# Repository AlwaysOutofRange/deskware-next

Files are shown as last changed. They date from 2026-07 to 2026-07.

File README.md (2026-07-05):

# DeskWare Next

A modular, fully parameterized fork of DeskWare (design by Hands on Katie,
OpenSCAD by BlackjackDuck). Same design language, new architecture: every
part is generated from parameters, so storage systems of **any dimensions**
can be produced — no more fixed 196 mm plates. With default settings, parts
remain print-interchangeable with original DeskWare.

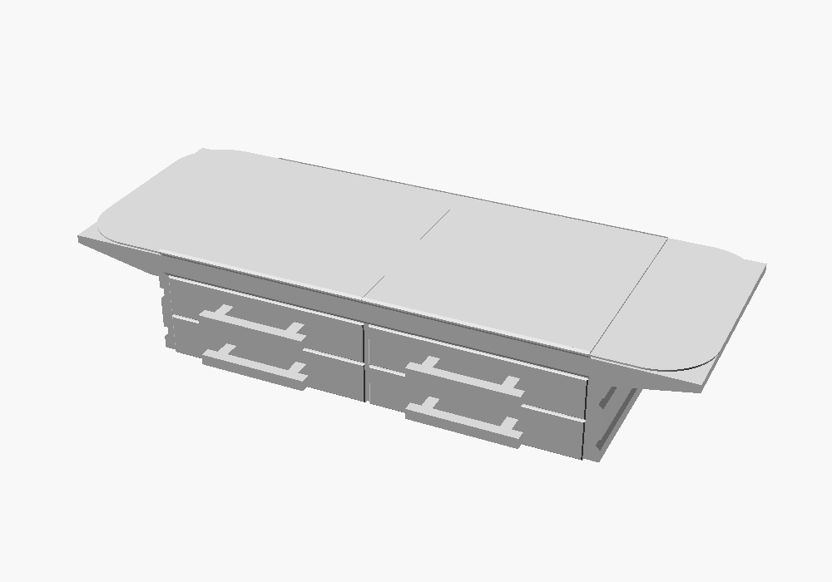
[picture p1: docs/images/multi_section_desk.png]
Two-section desk system


## Requirements

- OpenSCAD (recent version; developed against 2026.06)
- [BOSL2](https://github.com/BelfrySCAD/BOSL2) on the OpenSCAD library path
- The experimental `roof` feature enabled (GUI: Preferences → Features →
  roof; CLI: `--enable=roof`) — the end caps use it, and OpenSCAD silently
  renders them incomplete without it

## Quick start

```scad
include <deskware-next.scad>

//a whole system in one call...
storage_system(sections = 2, width = 196, depth = 196.5, total_height = 107.5);

//...or any single part at any size
base_plate(width = 250);
drawer(height_units = 2, rows = 2, columns = 3);

//too big for your printer? cut it, with mating connectors at the seams
split_part(size = [420, 211, 9.5], gap = 20)
    top_plate(width = 420, anchor=BOT);
```

Or open **`examples/customizer.scad`** in OpenSCAD and use the Customizer
panel: pick a part, set the dimensions, export.

Defaults live in [`config.scad`](config.scad) — including your print bed
size (`MAX_PRINT_WIDTH`/`MAX_PRINT_DEPTH`); parts warn when they exceed it.
The full API is documented in [`docs/reference.md`](docs/reference.md).

### Single-file build

Platforms like MakerWorld's parametric maker lab accept only one `.scad`
file. `tools/flatten.py` inlines all project includes (keeping the BOSL2
ones, which such platforms provide) into a self-contained, geometrically
identical build. Framework internals are hidden from the Customizer panel;
`--expose` keeps a file's sections visible — exposing `config.scad` gives
the full options panel (walls, top plate, drawer mounting, colors, …):

```bash
python3 tools/flatten.py examples/customizer.scad -o build/deskware-next-makerworld.scad \
    --expose config.scad \
    --hide-section "Core Dimensions" --hide-section "Print Bed" \
    --hide-section "End Style" --hide-section "Curve Sections" --hide-section "Connectors"
```

(The hidden sections are the ones the customizer entry re-exposes with its
own parameters, plus ones meaningless on an online platform.)

## Examples

| | |
| --- | --- |
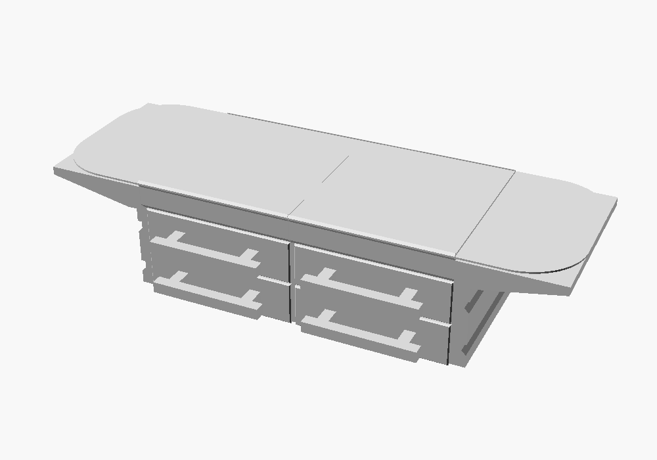
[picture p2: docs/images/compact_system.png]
|  **[multi_section_desk](examples/multi_section_desk.scad)** — the classic two-section desk system, one `storage_system()` call |  **[compact_system](examples/compact_system.scad)** — the same modules at 140 mm: every part prints whole on a small bed |
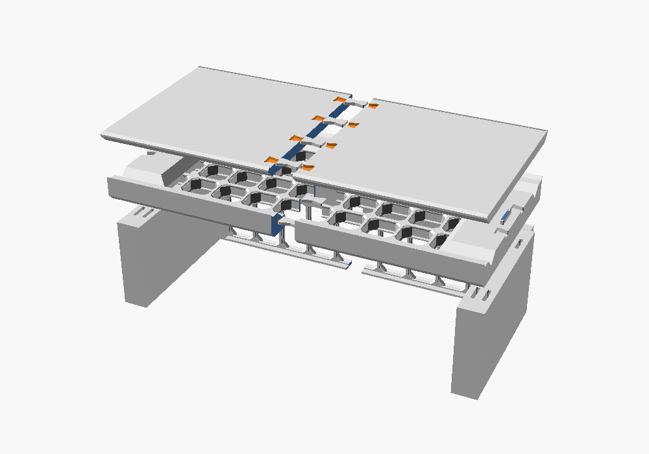
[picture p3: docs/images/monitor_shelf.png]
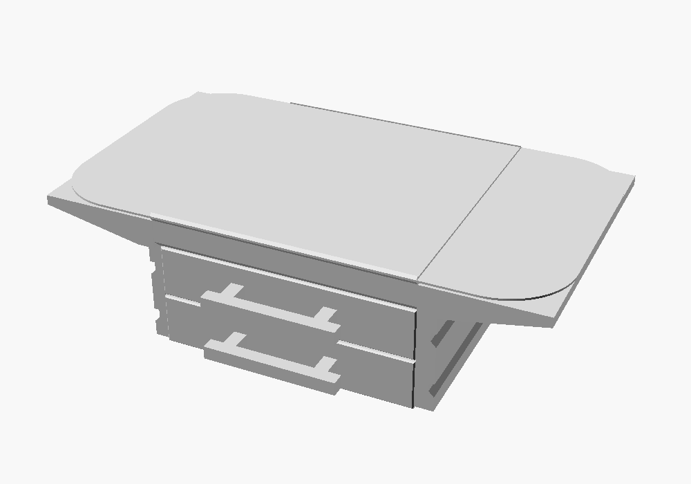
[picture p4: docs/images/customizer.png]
|  **[monitor_shelf](examples/monitor_shelf.scad)** — a 300 mm shelf, plates and backer auto-split with dovetail keys |  **[customizer](examples/customizer.scad)** — interactive part generator via the OpenSCAD Customizer |
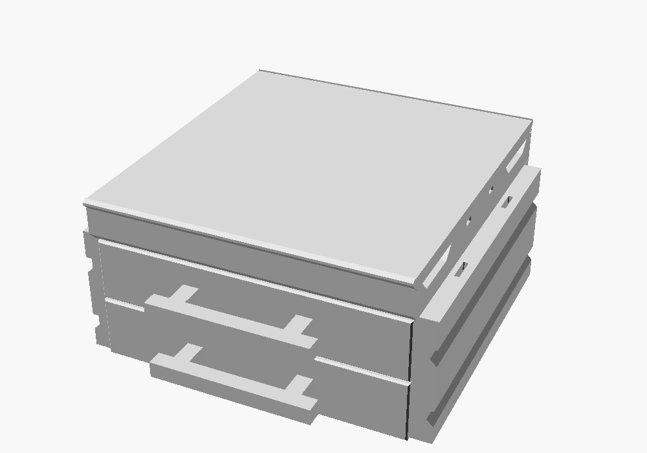
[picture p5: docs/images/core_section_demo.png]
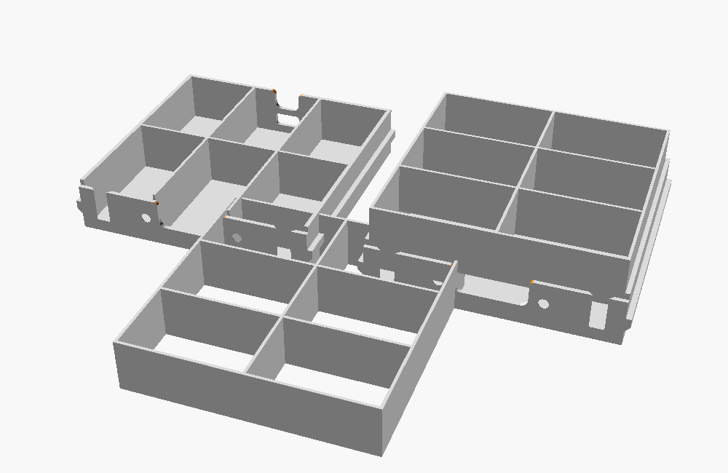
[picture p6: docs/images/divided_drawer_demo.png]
|  **[core_section_demo](examples/core_section_demo.scad)** — one full core section, placements derived from config |  **[divided_drawer_demo](examples/divided_drawer_demo.scad)** — built-in `rows × columns` compartments and the drop-in `divider_insert()` |
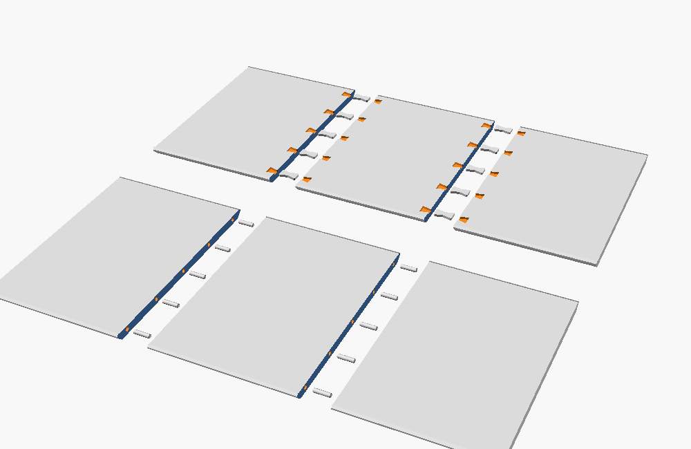
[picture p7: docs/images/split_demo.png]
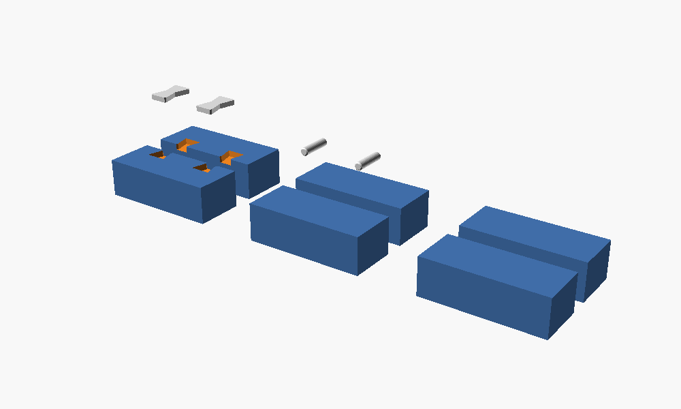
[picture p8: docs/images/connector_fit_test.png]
|  **[split_demo](examples/split_demo.scad)** — a 420 mm top plate split two ways (dovetails / hidden dowels) |  **[connector_fit_test](examples/connector_fit_test.scad)** — printable fit coupons for every seam connector style |
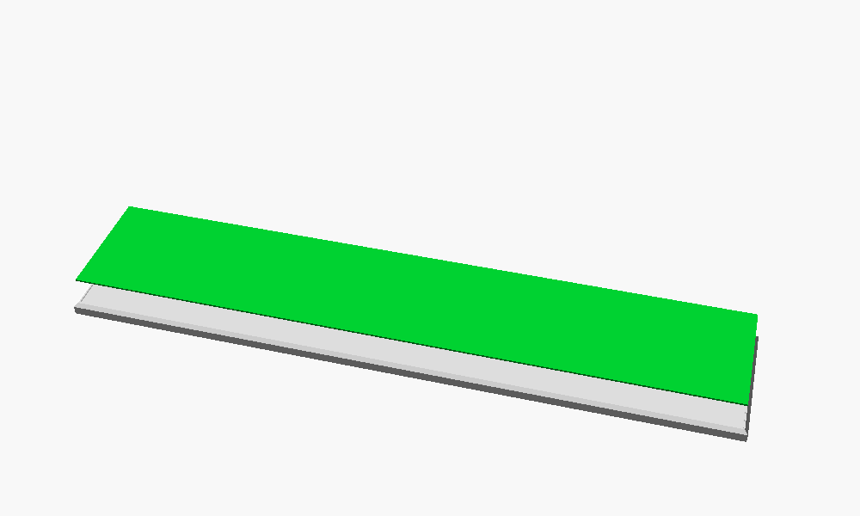
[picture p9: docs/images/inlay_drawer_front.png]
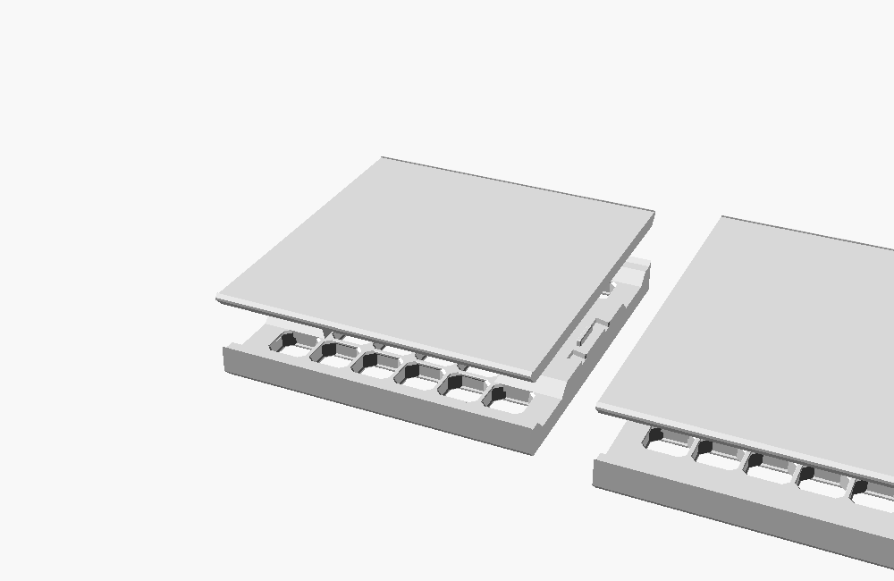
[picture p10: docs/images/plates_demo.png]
|  **[inlay_drawer_front](examples/inlay_drawer_front.scad)** — recessed drawer front with a printable contrast inlay |  **[plates_demo](examples/plates_demo.scad)** — base + top plates at default and arbitrary dimensions |
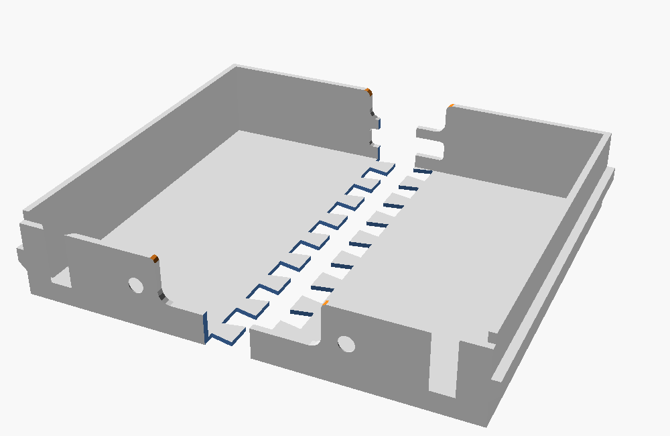
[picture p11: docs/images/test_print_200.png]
|  **[test_print_200](examples/test_print_200.scad)** — a complete 200 mm test system pre-split for a 175 mm bed: 2×2 grid splits with hidden dowels, puzzle glue seams for thin walls | |

## Structure

| Path | Contents |
| --- | --- |
| `config.scad` | User-facing parameters (dimensions, clearances, print bed, connectors, colors) |
| `core/` | Fixed system constants, pure derivation functions, print-fit checks, split system |
| `geometry/` | 2D cross-section profiles and sweep helpers |
| `connectors/` | HOK connectors, dovetails, dowels, magnets, tabs, slides, screws, seam joint API |
| `modules/` | The parts: plates, end caps, drawers + fronts, handle, riser, backer, dividers, `storage_system()` |
| `vendor/` | openGrid tiles (by David D), ported verbatim |
| `tools/` | Build helpers: `flatten.py` single-file build for MakerWorld-style platforms |
| `examples/` | Ready-to-render demos (see gallery above) |
| `docs/` | [Reference](docs/reference.md) and gallery images |
| `legacy/` | The original monolithic sources, unmodified — the regression oracle |

## Milestone status

- [x] **M1** — project structure, configuration system, shared utilities
- [x] **M2** — dynamic base/top plate generators
- [x] **M3** — dynamic drawer generator (plus riser and backer, completing the core section)
- [x] **M4** — dynamic divider system (`drawer(rows, columns)` + drop-in `divider_insert()`)
- [x] **M5** — connector system (`CONNECTOR_STYLE`-dispatched seam joints: dovetail, dowel, magnet)
- [x] **M6** — accessories: skipped by design — the plates carry standard openGrid fields, so the existing openGrid accessory ecosystem drops straight in
- [x] **M7** — automatic split generation for oversized parts (`split_part()` with seam connectors)
- [x] **M8** — documentation and examples

## Fidelity to the original

Every ported part was verified against the original sources (preserved in
[`legacy/`](legacy/)): STL exports at default dimensions match with zero
volume and bounding-box deltas, so DeskWare Next parts mate with original
DeskWare prints. See the provenance section of the
[reference](docs/reference.md).

## AI disclosure

The DeskWare Next refactor was written with substantial help from
[Claude Code](https://claude.com/claude-code), Anthropic's coding agent —
under human direction, with every part verified against the original
sources and validated in test prints.

## License

CC BY-NC-SA 4.0, inherited from the original DeskWare. See
[LICENSE.md](LICENSE.md) for attribution.

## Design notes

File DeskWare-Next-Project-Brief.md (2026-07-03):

# DeskWare Next -- Project Brief

## Overview

We are creating **DeskWare Next**, a fork of the original DeskWare
OpenSCAD project.

The goal is **not** to redesign the appearance of DeskWare. The goal is
to make the codebase modular, maintainable, and fully parameterized
while keeping the original design language.

DeskWare Next should allow users to generate storage systems of **any
dimensions**, instead of relying on fixed plate sizes like 196 mm.

------------------------------------------------------------------------

## Core Goals

-   Modular architecture
-   Clean OpenSCAD code
-   Minimal duplicated code
-   No magic numbers
-   Everything driven by parameters
-   Easy to extend
-   Easy to maintain
-   Easy to create new accessories

------------------------------------------------------------------------

## Design Philosophy

Instead of many specialized modules:

``` scad
drawer_small()
drawer_large()
drawer_xl()
plate_196()
plate_half()
```

Everything should become generic.

Example:

``` scad
plate(
    width = 180,
    depth = 180
);

drawer(
    width = 180,
    depth = 180,
    height = 60,
    rows = 2,
    columns = 3
);
```

------------------------------------------------------------------------

## Main Configuration

Every important dimension should come from a single configuration file.

Example:

``` scad
PLATE_WIDTH
PLATE_DEPTH

WALL_THICKNESS
BOTTOM_THICKNESS

CLEARANCE

CORNER_RADIUS

GRID_SIZE

MAGNET_DIAMETER
MAGNET_HEIGHT

PRINT_BED_SIZE

CONNECTOR_STYLE
```

Nothing should depend on hardcoded values.

------------------------------------------------------------------------

## Dynamic System

Every object should calculate its own dimensions.

Examples include:

-   Drawer wall spacing
-   Divider spacing
-   Grid placement
-   Clip locations
-   Magnet positions
-   Screw positions
-   Finger cutouts
-   Corner radii

All of these should derive from the parent object's dimensions.

------------------------------------------------------------------------

## Printer Independence

DeskWare Next should not assume any printer size.

Instead:

``` scad
MAX_PRINT_WIDTH
MAX_PRINT_DEPTH
```

If an object exceeds these dimensions it should automatically support
splitting into multiple printable pieces.

Future split methods:

-   Dowels
-   Dovetails
-   Puzzle joints
-   Magnet alignment

------------------------------------------------------------------------

## File Structure

``` text
deskware-next/

config.scad

core/
    constants.scad
    math.scad
    utilities.scad

geometry/
    rounded_box.scad
    fillets.scad
    chamfers.scad

connectors/
    dovetail.scad
    dowel.scad
    magnets.scad

modules/
    plate.scad
    drawer.scad
    organizer.scad
    riser.scad

accessories/
    pen_holder.scad
    tray.scad
    bins.scad

examples/
```

No 90,000-line single file.

------------------------------------------------------------------------

## Coding Standards

Every module should:

-   Have a clear purpose
-   Accept parameters
-   Avoid global state
-   Avoid duplicated calculations
-   Use descriptive variable names
-   Document parameters

Example:

``` scad
module drawer(
    width,
    depth,
    height,
    wall,
    clearance,
    rows,
    columns
)
```

------------------------------------------------------------------------

## Compatibility

Maintain the visual identity of the original DeskWare where practical.

Existing accessories should be portable with minimal changes.

Do not intentionally change aesthetics unless necessary.

------------------------------------------------------------------------

## Long-Term Vision

DeskWare Next should become a reusable framework rather than a fixed
collection of models.

Future additions may include:

-   Modular cable management
-   Monitor risers
-   Keyboard trays
-   Laptop stands
-   Shelving
-   Pegboard integration
-   Tool holders
-   Gridfinity compatibility
-   Parametric organizers

------------------------------------------------------------------------

## Development Strategy

Development should happen in small milestones.

### Milestone 1

-   Project structure
-   Configuration system
-   Shared utility functions

### Milestone 2

-   Dynamic plate generator

### Milestone 3

-   Dynamic drawer generator

### Milestone 4

-   Dynamic divider system

### Milestone 5

-   Connector system

### Milestone 6

-   Accessories

### Milestone 7

-   Automatic split generation

### Milestone 8

-   Documentation and examples

------------------------------------------------------------------------

## Guiding Principle

If a number appears more than once, it probably belongs in a parameter
or a shared calculation.

Every feature should be designed so changing a single dimension
propagates naturally throughout the model.

The end result should feel less like a collection of individual models
and more like a **parametric desk organization framework**.

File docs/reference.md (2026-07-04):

# DeskWare Next — Reference

Everything is included through the umbrella file:

```scad
include <deskware-next.scad>
```

All part modules follow the same conventions: **UPPER_SNAKE names in
`config.scad` are defaults**, every dimension is a parameter, parts are
BOSL2 `attachable` (they take `anchor` / `spin` / `orient` and compose with
`attach()`), and derived placements come from the pure functions in
`core/math.scad`. With unchanged config defaults, parts are dimensionally
interchangeable with original DeskWare prints (verified against the
original sources preserved in `legacy/`).

---

## Configuration (`config.scad`)

| Parameter | Default | Meaning |
| --- | --- | --- |
| `PLATE_WIDTH` / `PLATE_DEPTH` | 196 / 196.5 | Core section size, riser center to riser center. Any value — grid fields and connector positions adapt. |
| `TOTAL_HEIGHT` | 107.5 | Bottom of the risers to the top of the top plate. |
| `MAX_PRINT_WIDTH` / `MAX_PRINT_DEPTH` | *your bed* | Print bed limits; parts warn when exceeded, `split_part()` fixes it. |
| `WALL_THICKNESS` / `BOTTOM_THICKNESS` | 3 / 2 | Drawer walls and floors. |
| `CLEARANCE` | 0.15 | Fit clearance between mating parts. |
| `DIVIDER_THICKNESS` | 2 | Drawer compartment divider walls. |
| `CORNER_RADIUS` | 50 | Corner rounding of "Rounded Square" end pieces. |
| `END_STYLE` | `"Rounded Square"` | End cap style: `Rounded`, `Squared`, `Rounded Square`. |
| `TOP_PLATE_*` | — | Thickness, insert recess depth, lip width, chamfer, seating clearance. |
| `DRAWER_*` | — | Mounting method (printed handle / screw pulls), front chamfer, inlay recess. |
| `CONNECTOR_STYLE` | `"dovetail"` | Seam joint style: `dovetail`, `dowel`, `magnet`. |
| `CONNECTOR_SPACING` | 50 | Target distance between seam connectors. |
| `MAGNET_DIAMETER` / `MAGNET_HEIGHT` | 6 / 2 | Disc magnets for magnet seams. |
| `DOWEL_DIAMETER` / `DOWEL_LENGTH` | 4 / 16 | Printed dowel pins for dowel seams. |
| `BASE_PLATE_THICKNESS`, `RISER_WIDTH`, `ADDITIONAL_TOP_PLATE_SUPPORT`, `CURVE_RADIUS`, `VERBOSE` | — | Advanced. |

Interop-critical values (openGrid 28 mm unit, Gridfinity 42 mm, HOK
connector profile, dovetail/tab/slide dimensions, plate interface geometry)
live in `core/constants.scad` and should not normally be changed.

## Parts (`modules/`)

Every module accepts more parameters than shown — open the file for the
full documented signature. Deviating dimensions re-derive everything
inside (grid counts, connector spacings, slide counts).

```scad
//a whole system in one call (display composition)
storage_system(sections = 2, width = 196, depth = 196.5, total_height = 107.5);

//plates
base_plate(width = PLATE_WIDTH, depth = base_plate_depth(PLATE_DEPTH, BASEPLATE_DEPTH_EXTENSION));
top_plate(width = PLATE_WIDTH, thickness = 8.5, recess = 1);

//core section structure
riser(slide_sides = "BOTH", height = 80, chamfer = 0);
riser_split(height1 = 80, height2 = 40);        //stepped-height riser halves
backer(width = PLATE_WIDTH, height = 80);

//end caps (style: "Rounded", "Squared", "Rounded Square")
base_plate_end(style = END_STYLE, side = LEFT);
top_plate_end(style = END_STYLE, side = RIGHT);

//drawers
drawer(height_units = 1, rows = 2, columns = 3);  //built-in compartments
drawer_front(height_units = 1, recess = false);
drawer_handle();
divider_insert(rows = 3, columns = 2);            //drop-in for printed drawers
divider_grid([160, 160, 35], rows = 2, columns = 4); //raw wall lattice
```

Drawer sizing: `drawer()` takes **outside** dimensions; the default width
spans the riser gap and the default interior rounds down to whole
Gridfinity units so bins drop in.

## Connectors (`connectors/`)

Built into parts (interop with original DeskWare): HOK connectors
(`hok_connector()`, printable, joins stacked parts), alignment tabs,
drawer slides, printed screws (`t_screw()`, `screw_socket_sm()`).

Seam joints, for splitting and side-by-side joining:

```scad
//negative space: subtract from BOTH halves of a seam (they mate by symmetry)
seam_connector_cutouts(style = CONNECTOR_STYLE, seam = [width, height]);
//the loose printed keys (dovetail keys / dowel pins; magnets print nothing)
seam_connector_keys(style = CONNECTOR_STYLE, seam = [width, height]);
```

Seam frame: seam plane = XZ, X along the seam, Z up from the part bottom,
parts occupy +Y/−Y. Primitives are also available directly:
`dovetail_male()` / `dovetail_female()` / `dovetail_socket_pair()`,
`dowel_pin()` / `dowel_hole()`, `magnet_pocket()`.

## Splitting oversized parts (`core/split.scad`)

```scad
split_part(size = [420, 211, 9.5],   //bbox of the child (anchor=BOT at origin)
           axis = "x",               //"x", "y", or "both" (grid split)
           style = "dovetail",       //dovetail, dowel, magnet, or puzzle
           cuts = undef,             //explicit cut positions (steer around features)
           seam = undef,             //[width, height]: height override for the joints
           keepout = 15,             //drop connectors this close to a crossing seam
           show_keys = true,         //render the loose keys next to each seam
           gap = 20)                 //explode distance (0 = assembled)
    top_plate(width = 420, anchor=BOT);
```

Derives the piece count from `MAX_PRINT_*`, subtracts mating seam cutouts
at every cut, and renders the loose keys. `axis="both"` grid-splits a part
that exceeds the bed in both directions, keeping connectors away from the
seam crossings. `style="puzzle"` cuts an interlocking glue seam through the
whole cross-section instead of using loose keys (exactly 2 pieces on one
axis) - the right choice for thin-walled parts like drawers, fronts, and
backers, where a key would poke through the walls. Use `seam=` where a part
is thinner at the cut (e.g. `[0, BASEPLATE_TILE_POCKET]` puts a base
plate's dowels in the solid floor under its grid well) and `cuts=` to keep
seams out of grid fields.

`examples/test_print_200.scad` exercises all of this: a complete
200 x 200.5 x 107.5 mm system where every part is pre-split for a
175 x 175 mm bed, selectable per print plate through the Customizer.

## Derivation functions (`core/math.scad`)

All pure, all explicit-input. The ones you'll actually reach for:

| Function | Gives you |
| --- | --- |
| `core_section_height(total, top_t, base_t)` | Riser/backer height from a total height. |
| `base_plate_depth(core_d, ext)` / `top_plate_depth(bp_d, chamfer, clr)` / `riser_depth(core_d, setback)` | Companion part depths. |
| `drawer_outside_width(core_w, riser_w)` / `drawer_outside_depth(...)` / `drawer_height(units, sep, clr)` | Drawer envelope. |
| `slide_count(riser_h, ...)` | Drawer slots on a riser. |
| `grid_units_fit(span, unit, margin)` / `grid_span(units, unit)` | Grid fitting. |
| `hok_spacing_depth(units, unit)` / `hok_spacing_back(units, unit)` | HOK cutout spacing (must match between stacked parts). |
| `compartment_size(span, count, wall)` | Divider compartment size. |
| `connector_positions(span, spacing, margin)` | Seam connector layout. |
| `split_count(span, max)` / `split_positions(span, n)` | Split planning. |

## Provenance and verification

The original monolithic sources are preserved unmodified in `legacy/` and
serve as the regression oracle: every ported part (plates, drawers,
fronts, handle, riser, backer, dovetails, T-screw) was exported to STL at
default dimensions alongside its legacy counterpart and matched with zero
volume and bounding-box deltas (boolean differences render empty).
openGrid is by David D, ported verbatim in `vendor/`. License: CC BY-NC-SA
4.0 — see [LICENSE.md](../LICENSE.md).

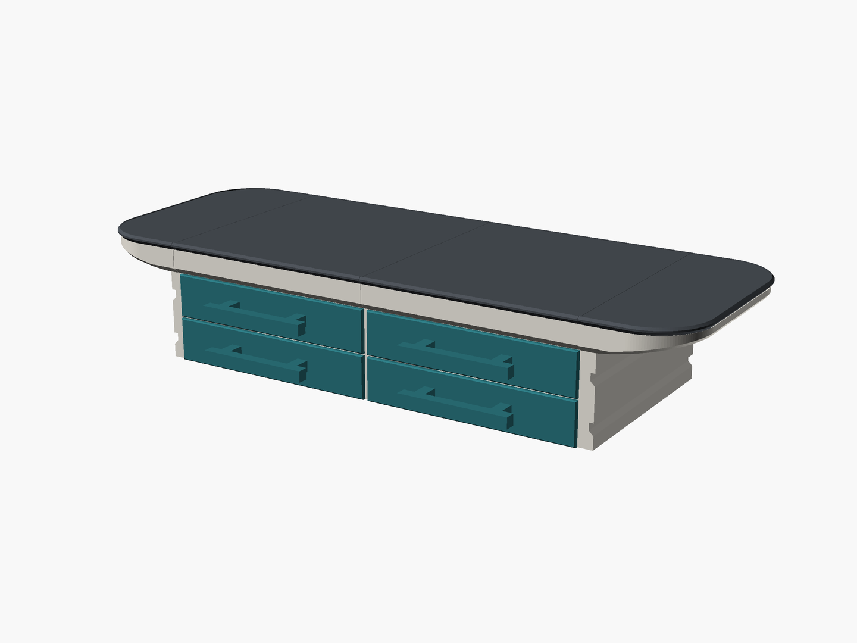
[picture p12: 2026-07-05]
docs/images/cover_app.png

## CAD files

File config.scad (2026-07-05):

/*
DeskWare Next - config.scad

User-facing configuration. Every value here is a default: part modules take
these as parameter defaults, so any single part can be generated at other
dimensions by passing arguments explicitly.

Expects core/constants.scad to be included first (deskware-next.scad does
this in the right order).

Licensed CC-BY-NC-SA 4.0. See LICENSE.md for attribution.
*/

/*[Core Dimensions]*/
//Width (mm) of one core section, riser center to riser center. Any value - no longer locked to 84mm increments.
PLATE_WIDTH = 196;
//Depth (mm) from the front of the riser to the rear of the backer.
PLATE_DEPTH = 196.5;
//Total height (mm) from the bottom of the riser to the top of the top plate.
TOTAL_HEIGHT = 107.5;

/*[Print Bed]*/
//Maximum printable width (mm) of your printer.
MAX_PRINT_WIDTH = 175;
//Maximum printable depth (mm) of your printer.
MAX_PRINT_DEPTH = 175;

/*[Walls and Fit]*/
//Wall thickness (mm) of drawers and boxes.
WALL_THICKNESS = 3;
//Floor thickness (mm) of drawers and boxes.
BOTTOM_THICKNESS = 2;
//Clearance (mm) between mating parts.
CLEARANCE = 0.15;
//Wall thickness (mm) of drawer compartment dividers.
DIVIDER_THICKNESS = 2;

/*[End Style]*/
//Style of the end pieces capping the outer sections.
END_STYLE = "Rounded Square"; //[Rounded, Squared, Rounded Square]
//Corner radius (mm) for rounded-square end pieces.
CORNER_RADIUS = 50;

/*[Top Plate]*/
//Thickness (mm) of the top plate body (recess depth is added on top).
TOP_PLATE_THICKNESS = 8.5;
//Depth (mm) of the recess in the top of the top plate. Match your insert material thickness for a flush top.
TOP_PLATE_RECESS = 1; //0.1
//Width (mm) of the top lip bordering the recess.
TOP_PLATE_LIP_WIDTH = 0.5;
//Chamfer (mm) at the top edge of the top plate.
TOP_PLATE_TOP_CHAMFER = 2;
//Lateral clearance (mm) between the top plate and the base plate.
TOP_PLATE_CLEARANCE = 1;

/*[Connectors]*/
//Joint style for seams between split or side-by-side parts. (HOK connectors handle stacking and are built into the parts themselves.)
CONNECTOR_STYLE = "dovetail"; //[dovetail, dowel, magnet]
//Target spacing (mm) between connectors along a seam.
CONNECTOR_SPACING = 50;
//Magnet diameter (mm) for magnet-style connections.
MAGNET_DIAMETER = 6;
//Magnet height (mm) for magnet-style connections.
MAGNET_HEIGHT = 2;
//Dowel pin diameter (mm) for dowel-style connections.
DOWEL_DIAMETER = 4;
//Dowel pin length (mm), split evenly across the seam.
DOWEL_LENGTH = 16;

/*[Drawers]*/
//Mounting method of the drawer pull (printed handle vs hardware screws).
DRAWER_MOUNTING = "Handle - Printed"; //[Screw Holes - Single, Screw Holes - Double, Handle - Printed]
//Chamfer (mm) of the drawer front edges.
DRAWER_FRONT_CHAMFER = 1;
//Screw diameter (mm) when using hardware drawer pulls (5mm is common).
DRAWER_PULL_SCREW_DIAMETER = 5;
//Distance (mm) between screw hole centers for double-screw pulls.
DRAWER_PULL_SCREW_SPACING = 75;
//Move the drawer pull holes up (positive) or down (negative) in mm.
DRAWER_PULL_HEIGHT_ADJUST = 0;
//Recess the drawer front for an inlay. Removes the dovetails (print orientation); glue the front to the box.
DRAWER_FRONT_RECESS = false;
//Depth (mm) of the front inlay recess.
DRAWER_FRONT_RECESS_DEPTH = 0.5;
//Inset (mm) of the front inlay recess from the front edges.
DRAWER_FRONT_RECESS_INSET = 0.4;

/*[Curve Sections]*/
//Inner radius (mm) of curved (arc) sections, measured from the riser face.
CURVE_RADIUS = 50;

/*[Colors]*/
PRIMARY_COLOR = "#dadada"; // color
TOP_PLATE_COLOR = "#dadada"; // color
DRAWER_FRONT_COLOR = "#dadada"; // color
DRAWER_HANDLE_COLOR = "#dadada"; // color

/*[Advanced]*/
//Thickness (mm) of the base plate.
BASE_PLATE_THICKNESS = 19;
//Width (mm) of the risers. Grid fit and drawer width derive from this.
RISER_WIDTH = 22;
//Extra reach of the top plate support built into the base plate, in grid units.
ADDITIONAL_TOP_PLATE_SUPPORT = 1; //[1:1:8]
//Echo extra diagnostic output while rendering.
VERBOSE = false;

/*[Hidden]*/
//Grid unit used for placement math. Alias of the openGrid unit from core/constants.scad.
GRID_SIZE = OPENGRID_UNIT;

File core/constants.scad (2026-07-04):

/*
DeskWare Next - core/constants.scad

Fixed system constants. These are properties of external systems (openGrid,
Gridfinity) or interoperability-critical dimensions of the original DeskWare
design language. Parts generated with these values mate with original
DeskWare prints. They are NOT user configuration - see config.scad for that.

Licensed CC-BY-NC-SA 4.0. See LICENSE.md for attribution.
*/

//---------- External grid systems ----------

//openGrid tile unit (design by David D)
OPENGRID_UNIT = 28;
//Full openGrid tile thickness
OPENGRID_TILE_THICKNESS = 6.8;
//openGrid Lite tile thickness
OPENGRID_LITE_TILE_THICKNESS = 4;

//Gridfinity base unit
GRIDFINITY_UNIT = 42;

//---------- HOK connector (profile fixed for interop) ----------

//Thickness of the printed HOK connector and its cutout
HOK_CONNECTOR_THICKNESS = 3.0;
//Total width of the HOK connector cutout across its mirror axis
HOK_CONNECTOR_WIDTH = 17.8;
//Height (sweep length) of the HOK connector cutout
HOK_CONNECTOR_HEIGHT = 15.2;
//Distance from a part edge to the center of an HOK connector cutout
HOK_CONNECTOR_INSET = 4.5;

//---------- Baseplate dovetails ----------

DOVETAIL_SPACING = 40;
DOVETAIL_DEPTH = 3.15;
DOVETAIL_WIDTH = 10;
DOVETAIL_HEIGHT = 9;
DOVETAIL_CHAMFER = 0.6;
DOVETAIL_SLOP = 0.1;

//---------- Alignment tabs (top plate / backer-to-riser) ----------

TAB_WIDTH = 3;
TAB_DEPTH = 20;
TAB_CHAMFER = 0.5;
//Distance from part outside edge to the tab (TabDistanceFromOutsideEdge)
TAB_EDGE_INSET = 6;
//How far the tab protrudes above its host part (TabProtrusionHeight)
TAB_PROTRUSION = 4;

//---------- Plate interface geometry (DeskWare design language) ----------

//Chamfer where the top plate seats onto the base plate (Top_Bot_Plates_Interface_Chamfer)
INTERFACE_CHAMFER = 3;
//Minimum flat surface the top plate rests on, excluding the chamfer (Minimum_Flat_Resting_Surface)
MIN_RESTING_SURFACE = 7.5;
//Chamfer at the bottom front/back of the base plate
BASEPLATE_BOTTOM_CHAMFER = 5;
//Depth of the openGrid tile pocket in the base plate underside (Tile_Thickness)
BASEPLATE_TILE_POCKET = 11.5;
//How much deeper the base plate is than the core section (front overhang)
BASEPLATE_DEPTH_EXTENSION = 10.5;
//Front/back margin around the openGrid pocket in the base plate (Grid_Min_Depth_Clearance)
BASEPLATE_GRID_DEPTH_MARGIN = 18;
//How much shallower the riser is than the core section
RISER_SETBACK = 7.5;

//---------- Drawer slide profile (drawer rail <-> riser recess interop) ----------

//Width (and rise of angle) of the slide recess
SLIDE_WIDTH = 4;
//Total height of the slide recess
SLIDE_HEIGHT = 10.5;
//Vertical distance between slides (one drawer height unit)
SLIDE_SEPARATION = 40;
//Distance from the bottom of the riser to the bottom of the slide recess
SLIDE_FROM_BOTTOM = 11.75;
//Minimum clearance from the top of a slide to the top of the riser
SLIDE_MIN_FROM_TOP = 16.75;
//Clearance between the drawer rail and the riser recess
SLIDE_CLEARANCE = 0.25;

//---------- Drawer interop dimensions ----------

//Vertical clearance between the drawer body and its height allotment
DRAWER_VERTICAL_CLEARANCE = 1.5;
//Vertical microadjustment of the drawer rail relative to the slide
DRAWER_SLIDE_MICROADJUST = 0.5;
//Dovetails joining the drawer front to the drawer box
DRAWER_DOVETAIL_WIDTH = 10;
DRAWER_DOVETAIL_HEIGHT = 25;
//Thickness of the drawer front panel
DRAWER_FRONT_THICKNESS = 3.5;
//The drawer box front wall is this much shorter for the front panel to overlap
DRAWER_FRONT_HEIGHT_REDUCTION = 4.5;
//Center-to-center spacing of the printed handle's screw connections
HANDLE_SCREW_SPACING = 70;
//Lateral gap between the drawer front panel and the section edges
DRAWER_FRONT_LATERAL_CLEARANCE = 2;

//---------- Backer interop dimensions ----------

BACKER_THICKNESS = 12.5;
//Depth of the cutouts that let the risers overlap the backer sides
BACKER_SIDE_CUTOUT_DEPTH = 3.65;
//Inset and depth of the backer-to-riser alignment tabs
BACKER_TAB_INSET = 2;
BACKER_TAB_DEPTH = 8;
//Solid base below the backer's openGrid field
BACKER_GRID_FROM_BOTTOM = 2;
//Minimum solid space above the backer's openGrid field
BACKER_GRID_TOP_MARGIN = 2;
//If less than this remains above the grid, reinforcement blocks back the
//HOK connector cutouts
BACKER_HOK_SAFE_CLEARANCE = 17;

//---------- End piece geometry (DeskWare design language) ----------

//Upward tilt angle of the squared end's outer face
END_ANGLE = 11;
//Width of the angled slab that forms the squared end
END_ANGLE_DISTANCE = 89;
//Bevel of the angled slab
END_BEVEL = 5;
//Resulting horizontal reach of a squared end piece
END_LATERAL_WIDTH = cos(END_ANGLE) * END_ANGLE_DISTANCE;
//Corner rounding of the "Squared" style (the sharp variant)
END_SQUARED_RADIUS = 1;
//Curve resolution ($fn) for rounded end pieces
END_CURVE_RESOLUTION = 100;

//---------- Small printed screw thread profile ----------

//Distance between threads
SCREW_SM_PITCH = 3;
//Diameter at the outer threads
SCREW_SM_OUTER_DIAMETER = 6.747;
//Angle of one side of the thread
SCREW_SM_FLANK_ANGLE = 60;
//Depth of the thread
SCREW_SM_THREAD_DEPTH = 0.5;
//Diameter of the hole down the middle of the screw
SCREW_SM_INNER_HOLE = 3.3;

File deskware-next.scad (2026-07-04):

/*
DeskWare Next
A modular, fully parameterized fork of DeskWare.

Original design by Hands on Katie, OpenSCAD by BlackjackDuck (Andy),
openGrid by David D. Licensed CC-BY-NC-SA 4.0 - see LICENSE.md.

Include this file to get the whole framework:

    include <deskware-next.scad>

    base_plate();                       // default dimensions from config.scad
    top_plate(width = 250, depth = 220); // or any dimensions you like
*/

include <BOSL2/std.scad>
include <BOSL2/rounding.scad>
include <BOSL2/joiners.scad>
include <BOSL2/threading.scad>

include <core/constants.scad>
include <config.scad>
include <core/math.scad>
include <core/utilities.scad>
include <core/split.scad>

include <geometry/profiles.scad>
include <geometry/extrusions.scad>

include <connectors/hok.scad>
include <connectors/dovetail.scad>
include <connectors/dowel.scad>
include <connectors/magnets.scad>
include <connectors/tabs.scad>
include <connectors/slides.scad>
include <connectors/screws.scad>
include <connectors/connectors.scad>

include <vendor/opengrid.scad>

include <modules/base_plate.scad>
include <modules/top_plate.scad>
include <modules/end_caps.scad>
include <modules/dividers.scad>
include <modules/drawer.scad>
include <modules/drawer_handle.scad>
include <modules/riser.scad>
include <modules/backer.scad>
include <modules/section.scad>

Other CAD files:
connectors/connectors.scad
connectors/dovetail.scad
connectors/dowel.scad
connectors/hok.scad
connectors/magnets.scad
connectors/screws.scad
connectors/slides.scad
connectors/tabs.scad
core/math.scad
core/split.scad
core/utilities.scad
examples/compact_system.scad
examples/connector_fit_test.scad
examples/core_section_demo.scad
examples/customizer.scad
examples/divided_drawer_demo.scad
examples/inlay_drawer_front.scad
examples/monitor_shelf.scad
examples/multi_section_desk.scad
examples/plates_demo.scad
examples/split_demo.scad
examples/test_print_200.scad
geometry/extrusions.scad
geometry/profiles.scad
legacy/HOK Connector.scad
legacy/deskware.scad
modules/backer.scad
modules/base_plate.scad
modules/dividers.scad
modules/drawer.scad
modules/drawer_handle.scad
modules/end_caps.scad
modules/riser.scad
modules/section.scad
modules/top_plate.scad

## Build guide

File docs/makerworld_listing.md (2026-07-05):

# MakerWorld listing

Upload notes: license **CC BY-NC-SA 4.0**, published as a **remix** of the
original DeskWare listing. Covers: `docs/images/cover_web.png` (16:9) and
`docs/images/cover_app.png` (4:3).

## Title

DeskWare Next — fully parametric DeskWare (any size)

## Description

**DeskWare, rebuilt as a fully parametric framework.** This is a remix of
DeskWare (design by Hands on Katie, OpenSCAD by BlackjackDuck) with the same
design language and the same interfaces — but every part is generated from
parameters. Build storage systems at **any width, depth, and height** instead
of fixed 196 mm plates. With default settings, parts are dimensionally
identical to original DeskWare and mix freely with existing prints.

**Using the customizer**

Pick a **Part** and export it — the *assembly* entry is a display preview of
the whole system, not a print file. Then customize:

- Free millimeter dimensions: section width, depth, total height
- End caps: Rounded / Squared / Rounded Square, adjustable corner radius
- Drawers: built-in compartments (rows × columns), drop-in divider inserts, printed handle or hardware screw pulls (single/double), front inlay recess for multi-color fronts
- Risers: slides on both/one/no sides, front chamfer, stepped split-height riser
- Top plate: recess depth and lip to fit your insert material (felt, veneer, acrylic…)
- Walls, clearances, and per-part colors

**What to print** (system of N sections)

- 1 base plate + 1 top plate per section
- N+1 risers, 1 backer per section
- Per drawer slot: drawer + front (+ handle or screws)
- 2 base plate ends + 2 top plate ends (left and right are the same print)

Standard heights 67.5 / 107.5 / 147.5 mm give 1 / 2 / 3 drawer slots per
section — but any height works; the generator tells you what fits. Drawer
interiors round to whole 42 mm Gridfinity units so bins drop straight in,
and the plates carry standard openGrid fields, so the whole openGrid
accessory ecosystem snaps on.

No supports needed — everything prints in its designed orientation.

**Part too big for your bed?** The full framework on GitHub also
auto-splits oversized parts with mating connectors (dovetail keys, hidden
dowels, or puzzle glue seams):
https://github.com/AlwaysOutofRange/deskware-next

**Credits**

- Design: Katie of Hands on Katie (YouTube, Patreon, Discord)
- Original OpenSCAD: BlackjackDuck (Andy)
- openGrid: David D, with optimization by Pedro Leite
- Parametric refactor: AlwaysOutofRange, written with substantial help from Claude Code

Licensed CC BY-NC-SA 4.0, inherited from the original DeskWare.

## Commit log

2026-07-03 Import original DeskWare sources into legacy/
    Original deskware.scad v1.6 (design by Hands on Katie, OpenSCAD by
    BlackjackDuck, openGrid by David D) and the standalone HOK Connector,
    preserved unmodified as reference and regression oracle for the
    DeskWare Next refactor.
    Licensed CC-BY-NC-SA 4.0 per the original headers.
    [HOK Connector.scad, deskware.scad]
2026-07-03 Milestone 1: project structure, config system, core utilities
    - config.scad: user-facing defaults incl. MAX_PRINT_WIDTH/DEPTH replacing
    the hardcoded printer table; dimensions freed from 84mm increments
    - core/constants.scad: interop-critical system constants (openGrid,
    Gridfinity, HOK profile, dovetails, tabs, plate interface geometry)
    - core/math.scad: pure derivation functions ported from the monolith's
    file-scope calc block; verified value-for-value against the original
    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
    [config.scad, constants.scad, deskware-next.scad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]
2026-07-04 Milestone 2: dynamic base/top plate generators
    - geometry/profiles.scad: plate cross-sections as pure point-list functions
    - geometry/extrusions.scad: unified straight/arc sweep_profile (dedupes the
    four duplicated path_sweep branches) + top_plate_from_shape for end caps
    - connectors/: HOK printable connector + cutout, dovetails, alignment tabs
    - vendor/opengrid.scad: openGrid by David D, verbatim port; fixes the
    undefined Screw_* / Full_or_Lite globals by making them parameters
    - modules/base_plate.scad, modules/top_plate.scad: fully parameterized;
    grid counts, HOK spacing, supports and tabs all derive from width/depth
    - examples/plates_demo.scad: default 196mm stack next to a 250x220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
    [base_plate.scad, config.scad, deskware-next.scad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]
2026-07-04 Milestone 3: dynamic drawer generator, riser, and backer
    - modules/drawer.scad: drawer box + front panel with outside-dimension API;
    interior rounds to whole Gridfinity units, all cutouts derive from parent
    dimensions (the original's clearance arithmetic cancels to width =
    core_width - riser_width, so the API drops the double-negative)
    - modules/drawer_handle.scad + connectors/screws.scad: printed handle,
    threaded socket, and T-screw
    - connectors/slides.scad + slide profiles: shared drawer-rail/riser-recess
    interface
    - modules/riser.scad: riser with derived slide count and HOK spacing, plus
    riser_split for stepped-height sections
    - modules/backer.scad: openGrid rear panel with de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
    [backer.scad, config.scad, constants.scad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]
2026-07-04 Milestone 4: dynamic divider system
    - modules/dividers.scad: divider_grid() reusable wall lattice and
    divider_insert(), a floorless friction-fit tray that retrofits
    already-printed drawers (optional floor via floor_thickness)
    - drawer() gains rows/columns/divider_thickness/divider_height, realizing
    the brief's drawer(width, depth, rows, columns) design example
    - compartment_size() in core/math.scad; DIVIDER_THICKNESS in config
    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
    [config.scad, deskware-next.scad, divided_drawer_demo.scad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]
2026-07-04 Milestone 5: connector system
    - connectors/dowel.scad: printable dowel_pin + dowel_hole
    - connectors/magnets.scad: press-fit magnet_pocket (MAGNET_* config)
    - connectors/dovetail.scad: dovetail_socket_pair, the seam negative that
    mates the existing double-male key
    - connectors/connectors.scad: seam joint API - seam_connector_cutouts()
    and seam_connector_keys() dispatch on CONNECTOR_STYLE and lay out
    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
    [config.scad, connector_fit_test.scad, connectors.scad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]
2026-07-04 Milestone 7: automatic split generation (M6 accessories deferred)
    - core/split.scad: split_part(size, axis, ...) cuts any child part into
    as few bed-sized pieces as fit (split_count/split_positions in core/math),
    subtracts mating seam_connector_cutouts at every cut, and renders the
    loose keys - assembled, or exploded via gap. cuts= steers seams away
    from features; seam= adapts the joint cross-section to thinner regions
    - check_printable() oversize warning now points at split_part()
    - seam keys placed exactly flush (the 0.01 anti-z-fighting offset now
    applies only to cutouts)
    - examples/split_demo.scad: a 420mm top plate split two ways (dovetail
    keys and hidden dowels), exploded w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
    [connectors.scad, deskware-next.scad, math.scad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]
2026-07-04 Milestone 8: documentation and examples
    - modules/section.scad: storage_system() - a complete multi-section
    system in one call, wiring grid counts, HOK spacings, drawer sizes and
    slot counts consistently from shared width/depth/height arguments
    - five new examples: multi_section_desk (flagship), compact_system
    (140mm sections that print whole on small beds), monitor_shelf (300mm
    shelf with plates/backer auto-split), customizer (interactive part
    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
    [compact_system.scad, config.scad, customizer.scad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]
2026-07-04 End pieces: squared, rounded-square, and rounded caps
    - modules/end_caps.scad ports all four legacy end modules:
    base_plate_end_squared (tilted minkowski-stretched cap with dovetail
    sockets, tabs, HOK cutouts), base_plate_end_rounded (half-round, with
    legacy Oct/Hex bonus styles), top_plate_end_squared / _rounded (built
    on top_plate_from_shape), plus base_plate_end()/top_plate_end() style
    dispatchers
    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
    [config.scad, constants.scad, customizer.scad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]
2026-07-04 Grid and puzzle splits + 200mm test print kit
    split_part() grows two modes for the 175mm-bed test print:
    - axis="both": 2D grid split for parts exceeding the bed in both
    directions, with connectors dropped near seam crossings (keepout)
    and per-piece explode tracking for the loose keys
    - style="puzzle": interlocking glue seam through the whole cross-section
    via BOSL2 partition(), for thin-walled parts where a loose key would
    poke through (drawers, fronts, the 12.5mm backer). Teeth are sized to
    tile the entire cut line because the installed partition mask ends at
    the last tooth and would silently eat any straight remainder; the mask
    is also padded so $slop shrinkage can't shave t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
    [split.scad, test_print_200.scad]
2026-07-05 Mark M6 as skipped by design; credit refactor author
    The openGrid accessory ecosystem already covers accessories, so M6 is
    closed rather than built. All project-brief milestones are now done and
    print-validated.
2026-07-05 Add flatten.py: single-file builds for MakerWorld-style platforms
    Inlines all project includes into one self-contained .scad (BOSL2
    includes kept - the platform provides the library), hiding framework
    internals from the Customizer via a [Hidden] section per inlined file.
    Output verified byte-identical to the modular build across base plate,
    top plate end (roof path), and divided drawer STL exports.
2026-07-05 Customizer parity with the original DeskWare panel
    Expose what the framework already supported: end style + corner radius,
    riser options (slide sides, chamfer, stepped riser via riser_split),
    assembly display toggles and explode, and - through the single-file
    build - all of config.scad (walls, top plate, drawer mounting/recess,
    colors, advanced). storage_system() gains an end_radius pass-through;
    END_STYLE/CORNER_RADIUS move to their own config section so the entry
    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
    [config.scad, customizer.scad, section.scad]
2026-07-05 Add MakerWorld cover images (web 16:9, app 4:3)
    Rendered from the flattened build: two-section assembly, cream body,
    teal drawer fronts, charcoal top. 2x supersampled OpenSCAD renders,
    Tomorrow colorscheme:
    openscad --backend=Manifold --enable=roof --render --imgsize=3840,2160
    --colorscheme=Tomorrow --camera=0,0,46,72,0,32,1180
    -D 'Part="assembly"' -D 'Sections=2' -D 'PRIMARY_COLOR="#e7e3da"'
    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
